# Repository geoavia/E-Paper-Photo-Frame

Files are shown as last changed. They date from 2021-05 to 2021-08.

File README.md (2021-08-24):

# 7 color e-Paper Photo Frame

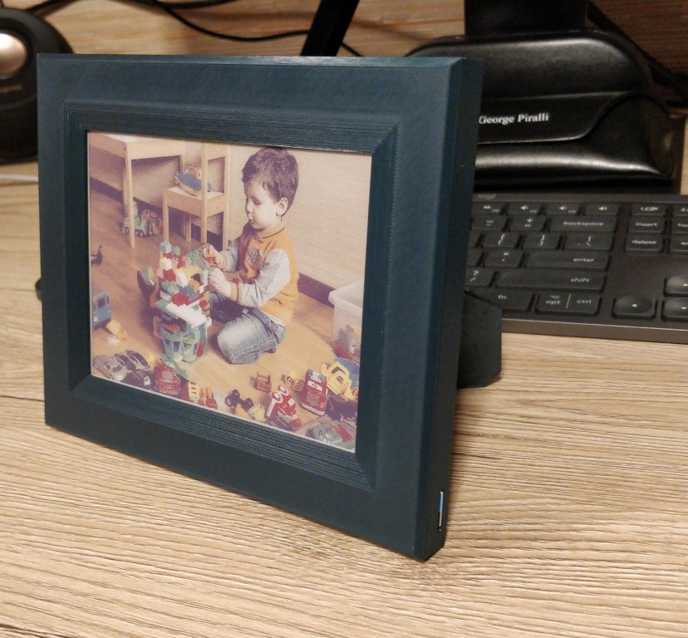
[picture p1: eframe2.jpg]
eFrame


Video of finished device: https://youtu.be/H_CAdMDsyxA

### Components used

* [Arduino Nano compatible board](https://www.amazon.com/dp/B07G99NNXL)
* [7 colour e-paper display panel](https://www.waveshare.com/product/displays/e-paper/epaper-1/5.65inch-e-paper-module-f.htm)
* [Micro SD card board](https://www.amazon.com/gp/product/B07BJ2P6X6)
* Resistors (100k x 2, 100 ohm, 1k)
* Integral circuit SI4542DY or similar (two mosfets in package).
* One LED, color of your preferance :)
* Single push button momentary switch
* 7v-12v battery pack

### e-Paper display connection
According to [waveshare wiki](https://www.waveshare.com/wiki/5.65inch_e-Paper_Module_(F)):<br>
e-Paper display | Arduino
------------ | -------------
Vcc | 5V
GND | GND
DIN | D11
CLK | D13
CS | D10
DC | D9
RST | D8
BUSY | D7

### SD Card board connection
SD card reader | Arduino
------------ | -------------
GND | GND
Vcc | 5V
MISO | D12
MOSI | D11
SCK | D13
CS | D4

### Power off circuit
Power off circuit based on [Indrek Luuk's article](https://circuitjournal.com/arduino-auto-power-off), but using single [SI4542DY IC](https://www.onsemi.com/pdf/datasheet/si4542dy-d.pdf) containing two (N and P channel) mosfets.<br>
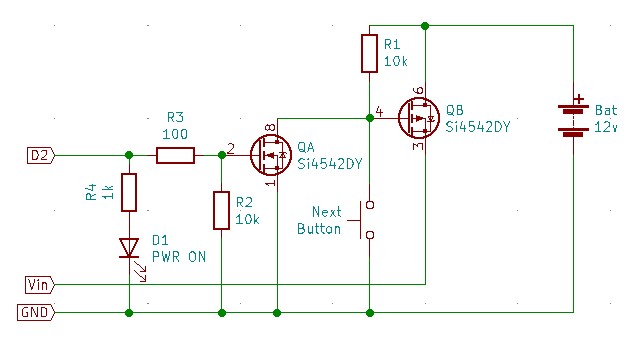
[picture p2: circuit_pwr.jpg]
Power off
<br><br>
I have utilized the [TSSOP16](https://www.amazon.com/dp/B00O9W6RLQ) adapter board (although any similar board will do).<br>
* [Adapter board and SI4542DY](https://github.com/geoavia/E-Paper-Photo-Frame/blob/main/ssop16_and_chip.jpg)
* [Circuit sheme on adapter board](https://github.com/geoavia/E-Paper-Photo-Frame/blob/main/ssop16.jpg)
* [Assembled power off circuit board](https://github.com/geoavia/E-Paper-Photo-Frame/blob/main/ssop16_assembled.jpg)

### Inside alignment
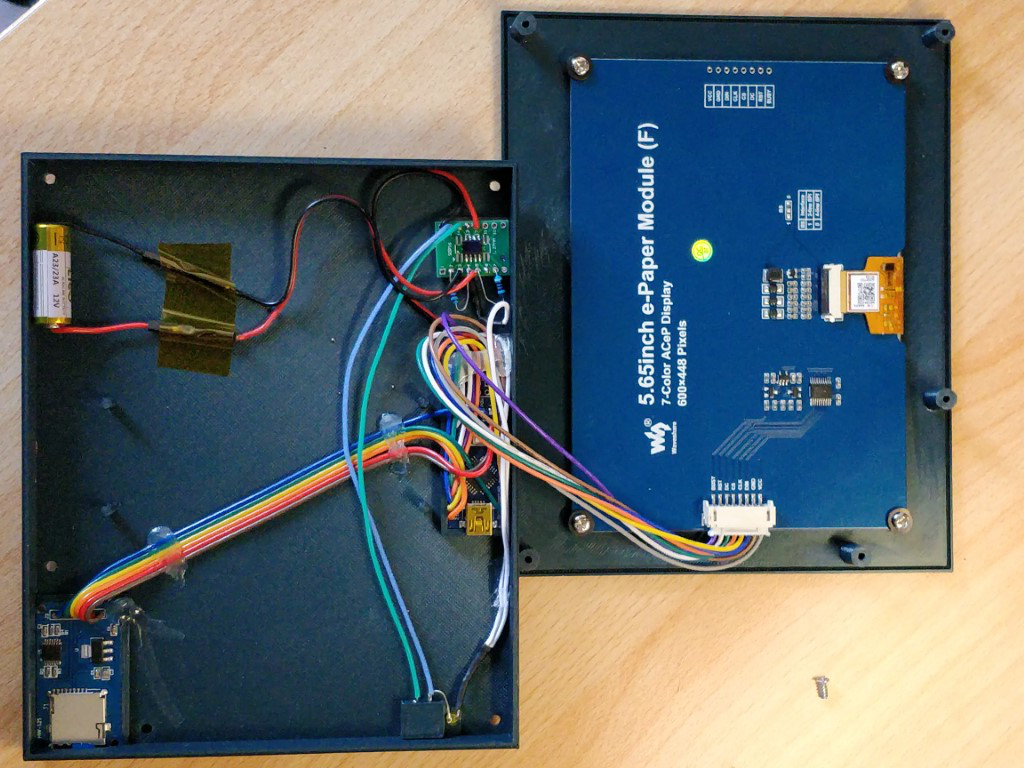
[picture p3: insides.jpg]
Inside
<br><br>

Enclosure case 3d model (Fusion 360) and stl files for print [are also provided](https://github.com/geoavia/E-Paper-Photo-Frame/tree/main/enclosure)<br>
You may also need some [brass threaded inserts](https://www.amazon.com/dp/B01IYWTCWW) for screen mounting (holes already cut in 3d model)

### Arduino sketch

[Complete Sketch folder](https://github.com/geoavia/E-Paper-Photo-Frame/tree/main/epaper7c)<br>

<details>
<summary>
Main sketch code here
</summary>

```C++
#include <SPI.h>
#include <SD.h>
#include "epd5in65f.h"

#define LOG_NAME "/log.inc"
#define MAX_NAME 32

// Shut down activate pin
const int shutDownPin = 2;

void setup() {

  pinMode(shutDownPin, OUTPUT);
  digitalWrite(shutDownPin, HIGH);   // power on

  // put your setup code here, to run once:
  Serial.begin(9600);

  Serial.print("Initializing SD card...");
  if (!SD.begin(4)) {
    Serial.println("failed!");
    delay(5000);
    exit(1);
  }
  Serial.println("done.");

  char imgFileName[MAX_NAME];
  unsigned long logSize = 0;

  memset(imgFileName, 0, MAX_NAME);

  File logFile = SD.open(LOG_NAME, FILE_WRITE);
  if (logFile) {
    logSize = logFile.size();
    Serial.print("Log size: ");
    Serial.println(logSize);
    logFile.write('.');
    logFile.close();
  }

  NextFileName(logSize, imgFileName);

  File imgFile = SD.open(imgFileName, FILE_READ);
  if (imgFile) {
    unsigned long fs = imgFile.size();
    Serial.print("Show image: ");
    Serial.print(imgFileName);
    Serial.print(" (");
    Serial.print(fs);
    Serial.println(" bytes)...");

    int x = 0;
    int y = 0;
    UBYTE bp;

    /////////////////////////////////////////////
    // start e-Paper code
    
    Epd epd;
    if (epd.Init() == 0) {
      Serial.println("e-Paper: init ok");

      epd.Clear(EPD_5IN65F_WHITE);
      Serial.println("e-Paper: clear");
      
      epd.SendCommand(0x61);//Set Resolution setting
      epd.SendData(0x02);
      epd.SendData(0x58);
      epd.SendData(0x01);
      epd.SendData(0xC0);
      epd.SendCommand(0x10);
  
      while (imgFile.available()) {
        bp = imgFile.read();
        epd.SendData(bp);
        x++;
        if (x == 300) {
          y++;
          x = 0;
        }
      }
  
      epd.SendCommand(0x04);//0x04
      epd.EPD_5IN65F_BusyHigh();
      epd.SendCommand(0x12);//0x12
      epd.EPD_5IN65F_BusyHigh();
      epd.SendCommand(0x02);  //0x02
      epd.EPD_5IN65F_BusyLow();
  
      Serial.println("e-Paper: image sent");

      epd.Sleep();
      Serial.println("e-Paper: sleep");
  
      // end e-Paper code
      /////////////////////////////////////////////
    } else {
      Serial.println("e-Paper: init failed!");
    }
    
    imgFile.close();
  } else {
    Serial.print("error opening image file: ");
    Serial.println(imgFileName);
    exit(1);
  }

  Serial.println("Complete");
  delay(2000);
}

void loop() {
  delay(5000);
  digitalWrite(shutDownPin, LOW);   // power off
}

void NextFileName(unsigned long logSize, char *fname) {
  int count = 0;
  File dir = SD.open("/");
  File file;
  // first loop for counting files...
  while (file = dir.openNextFile()) {
    if (file.isDirectory() || file.size() != 134400) {
      file.close();
      continue;
    }
    Serial.println(file.name());
    file.close();
    count++;
  }
  Serial.print("Total images: ");
  Serial.println(count);
  dir.rewindDirectory();
  logSize = logSize % count;
  count = 0;
  // ... and second loop for finding next file. I know its's wierd but it works :) 
  while (file = dir.openNextFile()) {
    if (file.isDirectory() || file.size() != 134400) {
      file.close();
      continue;
    }
    if (logSize == count) {
      strcpy(fname, file.name());
    }
    file.close();
    count++;
  }
  Serial.print("Current index: ");
  Serial.println(logSize);
  dir.close();  
}
```
</details>

### Preparing image files

1. Resize images to resolution of 600x448 pixels
2. Save them according to [this manual](https://www.waveshare.com/wiki/E-Paper_Floyd-Steinberg) (use 7 color version)
3. Convert each file with [converter](https://github.com/geoavia/E-Paper-Photo-Frame/tree/main/converter) utility (compile first)
4. Save resulting BIM files to SD card, obviousely :)

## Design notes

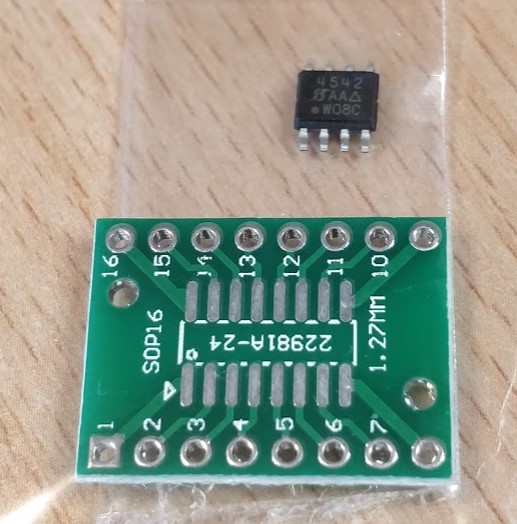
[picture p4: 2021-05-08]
ssop16_and_chip.jpg

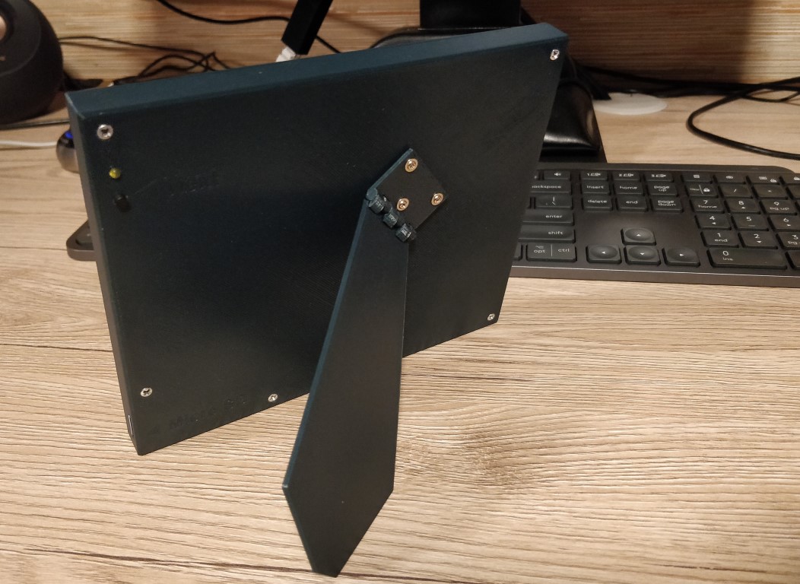
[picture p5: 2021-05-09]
eframe1.jpg

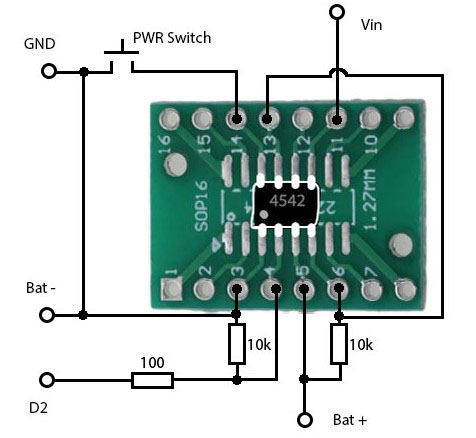
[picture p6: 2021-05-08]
ssop16.jpg

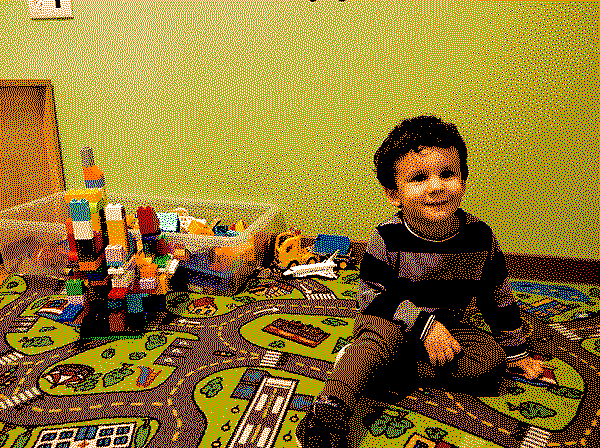
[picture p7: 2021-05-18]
converter/x86/sample1.gif

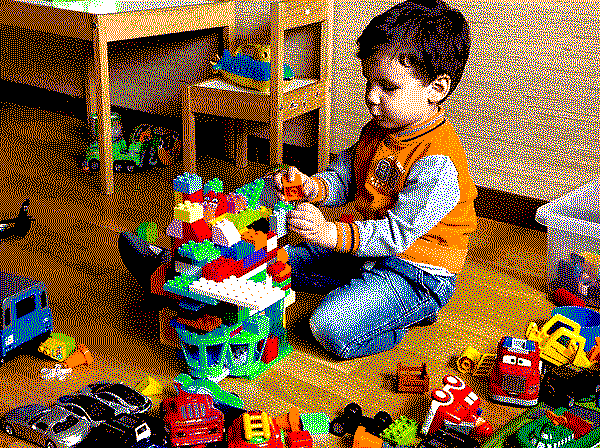
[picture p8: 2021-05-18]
converter/x86/sample2.gif

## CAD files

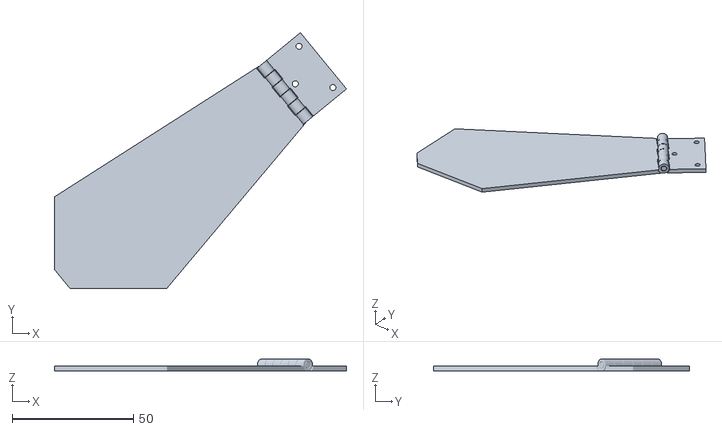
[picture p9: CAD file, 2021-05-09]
enclosure/eframe_stand.stl
120.4 x 105.5 x 4.99

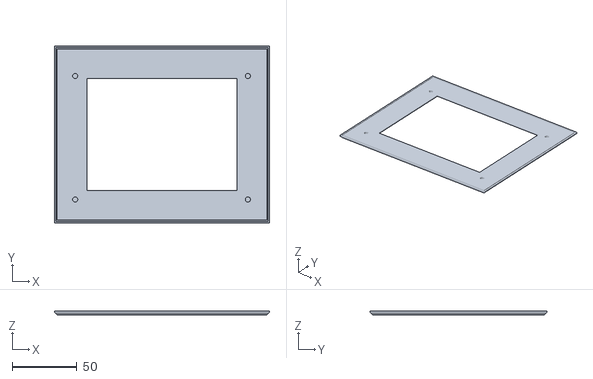
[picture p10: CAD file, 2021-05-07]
enclosure/eframe_front.stl
166.2 x 136.5 x 3.00

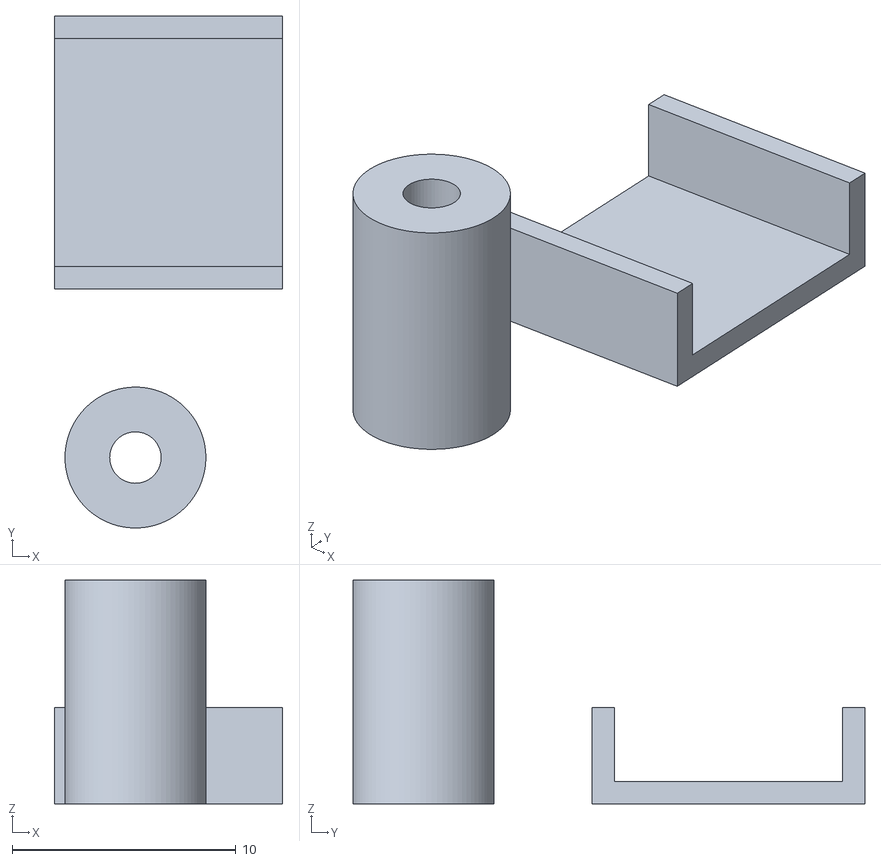
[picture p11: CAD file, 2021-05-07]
enclosure/eframe_misc.stl
10.2 x 22.9 x 10.0

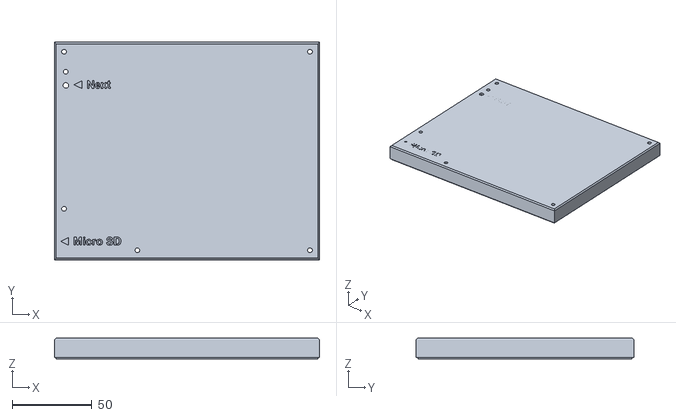
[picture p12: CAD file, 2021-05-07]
enclosure/eframe_back.stl
166.2 x 136.5 x 13.0

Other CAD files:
enclosure/e-Frame v12.f3d

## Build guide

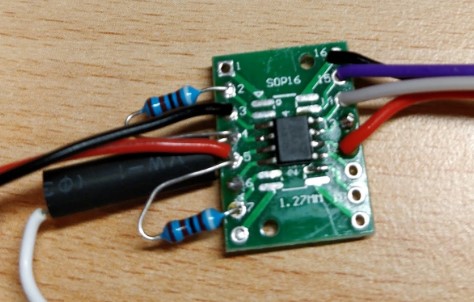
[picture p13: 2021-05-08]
ssop16_assembled.jpg

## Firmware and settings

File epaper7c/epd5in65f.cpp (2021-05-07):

/*****************************************************************************
* | File      	:   EPD_5in65f.c
* | Author      :   Waveshare team
* | Function    :   5.65inch e-paper
* | Info        :
*----------------
* |	This version:   V1.0
* | Date        :   2020-07-08
* | Info        :
* -----------------------------------------------------------------------------
#
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
******************************************************************************/

#include <stdlib.h>
#include "epd5in65f.h"

Epd::~Epd() {
};

Epd::Epd() {
    reset_pin = RST_PIN;
    dc_pin = DC_PIN;
    cs_pin = CS_PIN;
    busy_pin = BUSY_PIN;
    width = EPD_WIDTH;
    height = EPD_HEIGHT;
};

/******************************************************************************
function :  Initialize the e-Paper register
parameter:
******************************************************************************/
int Epd::Init(void) {
  if (IfInit() != 0) {
      return -1;
  }
  Reset();
    EPD_5IN65F_BusyHigh();
    SendCommand(0x00);
    SendData(0xEF);
    SendData(0x08);
    SendCommand(0x01);
    SendData(0x37);
    SendData(0x00);
    SendData(0x23);
    SendData(0x23);
    SendCommand(0x03);
    SendData(0x00);
    SendCommand(0x06);
    SendData(0xC7);
    SendData(0xC7);
    SendData(0x1D);
    SendCommand(0x30);
    SendData(0x3C);
    SendCommand(0x41);
    SendData(0x00);
    SendCommand(0x50);
    SendData(0x37);
    SendCommand(0x60);
    SendData(0x22);
    SendCommand(0x61);
    SendData(0x02);
    SendData(0x58);
    SendData(0x01);
    SendData(0xC0);
    SendCommand(0xE3);
    SendData(0xAA);
	
    DelayMs(100);
    SendCommand(0x50);
    SendData(0x37);
}

/**
 *  @brief: basic function for sending commands
 */
void Epd::SendCommand(unsigned char command) {
    DigitalWrite(dc_pin, LOW);
    SpiTransfer(command);
}

/**
 *  @brief: basic function for sending data
 */
void Epd::SendData(unsigned char data) {
    DigitalWrite(dc_pin, HIGH);
    SpiTransfer(data);
}

void Epd::EPD_5IN65F_BusyHigh(void)// If BUSYN=0 then waiting
{
    while(!(DigitalRead(BUSY_PIN)));
}

void Epd::EPD_5IN65F_BusyLow(void)// If BUSYN=1 then waiting
{
    while(DigitalRead(BUSY_PIN));
}

/**
 *  @brief: module reset.
 *          often used to awaken the module in deep sleep,
 *          see Epd::Sleep();
 */
void Epd::Reset(void) {
    DigitalWrite(reset_pin, LOW);                //module reset    
    DelayMs(1);
    DigitalWrite(reset_pin, HIGH);
    DelayMs(200);    
}

/******************************************************************************
function :  Sends the image buffer in RAM to e-Paper and displays
parameter:
******************************************************************************/
void Epd::EPD_5IN65F_Display(const UBYTE *image) {
    unsigned long i,j;
    SendCommand(0x61);//Set Resolution setting
    SendData(0x02);
    SendData(0x58);
    SendData(0x01);
    SendData(0xC0);
    SendCommand(0x10);
    for(i=0; i<height; i++) {
        for(j=0; j<width/2; j++) {
            SendData(image[j+((width/2)*i)]);
		}
    }
    SendCommand(0x04);//0x04
    EPD_5IN65F_BusyHigh();
    SendCommand(0x12);//0x12
    EPD_5IN65F_BusyHigh();
    SendCommand(0x02);  //0x02
    EPD_5IN65F_BusyLow();
	DelayMs(200);
}

/******************************************************************************
function :  Sends the part image buffer in RAM to e-Paper and displays
parameter:
******************************************************************************/
void Epd::EPD_5IN65F_Display_part(const UBYTE *image, UWORD xstart, UWORD ystart, 
                                        UWORD image_width, UWORD image_heigh)
{
    unsigned long i,j;
    SendCommand(0x61);//Set Resolution setting
    SendData(0x02);
    SendData(0x58);
    SendData(0x01);
    SendData(0xC0);
    SendCommand(0x10);
    for(i=0; i<height; i++) {
        for(j=0; j< width/2; j++) {
            if(i<image_heigh+ystart && i>=ystart && j<(image_width+xstart)/2 && j>=xstart/2) {
              SendData(pgm_read_byte(&image[(j-xstart/2) + (image_width/2*(i-ystart))]));
            }
			else {
				SendData(0x11);
			}
		}
    }
    SendCommand(0x04);//0x04
    EPD_5IN65F_BusyHigh();
    SendCommand(0x12);//0x12
    EPD_5IN65F_BusyHigh();
    SendCommand(0x02);  //0x02
    EPD_5IN65F_BusyLow();
	DelayMs(200);
}

/******************************************************************************
function : 
      Clear screen
******************************************************************************/
void Epd::Clear(UBYTE color) {
    SendCommand(0x61);//Set Resolution setting
    SendData(0x02);
    SendData(0x58);
    SendData(0x01);
    SendData(0xC0);
    SendCommand(0x10);
    for(int i=0; i<width/2; i++) {
        for(int j=0; j<height; j++) {
            SendData((color<<4)|color);
		}
	}
    SendCommand(0x04);//0x04
    EPD_5IN65F_BusyHigh();
    SendCommand(0x12);//0x12
    EPD_5IN65F_BusyHigh();
    SendCommand(0x02);  //0x02
    EPD_5IN65F_BusyLow();
    DelayMs(500);
}

/**
 *  @brief: After this command is transmitted, the chip would enter the 
 *          deep-sleep mode to save power. 
 *          The deep sleep mode would return to standby by hardware reset. 
 *          The only one parameter is a check code, the command would be
 *          You can use EPD_Reset() to awaken
 */
void Epd::Sleep(void) {
    DelayMs(100);
    SendCommand(0x07);
    SendData(0xA5);
    DelayMs(100);
	DigitalWrite(RST_PIN, 0); // Reset
}



/* END OF FILE */

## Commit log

2021-05-07 added 3d models
    [e-Frame v12.f3d, eframe_back.stl, eframe_front.stl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]
2021-05-07 power off circuit diagram
2021-05-18 Add files via upload
    compiled exe for windows, batch converter script and sample image
